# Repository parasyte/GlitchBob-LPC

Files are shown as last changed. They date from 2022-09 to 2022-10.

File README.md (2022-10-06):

# GlitchBob LPC

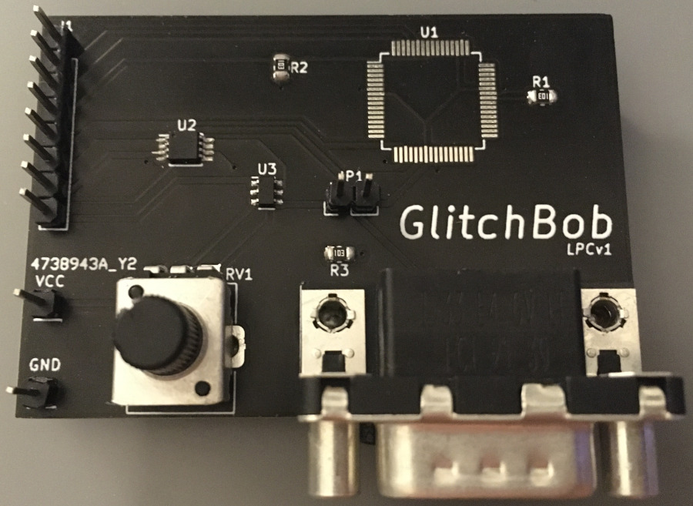
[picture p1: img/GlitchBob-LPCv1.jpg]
GlitchBob LPCv1 device fully assembled


Voltage glitching automation tool to break protection on NXP LPC microcontrollers.

The glitch circuit can be controlled by a Raspberry Pi Pico or other low-cost development board.

## TODO

These are issues identified in the prototype:

- Add bypass caps to all ICs.
- Add pull-up resistor to `74LVC1G3157` switch input.
- Add pull-down resistors to `74LVC2G66` switch inputs.
- Move target closer to I/O header to reduce the trace length for the oscillator I/O.
    - Shorter traces have lower impedance and will be capable of faster clock frequency (up to target max, e.g. 12 MHz).
- The potentiometer polarity is swapped.
    - 0v should be fully counterclockwise, and +VCC should be fully clockwise.
- The potentiometer is upside down.
    - Rotate the footprint 180 degrees.
- No good place to put the rubber feet.
    - Move through-hole components or find smaller feet.
- Still has some wasted surface area with traces spread out.
    - Change 8-pin header pinout to optimize routing.
    - Move traces closer together to prevent ground plane islands.
- `R3` is a bit too close to the serial port.
    - Move `R3` so it is more easily reachable for assembly.

And this is a wish-list for improvements:

- Replace 8-pin header with Raspberry Pi Pico header footprint.
- Add a 7-segment display for glitch-voltage display and other info.
    - 7-Segment driver can be inexpensively built with:
        - [`74LVC244`](https://www.mouser.com/ProductDetail/Texas-Instruments/SN74LVC244APWR?qs=DcvZ7Fltd5xns%252BvAsbES0A%3D%3D) or [`74HC244`](https://www.mouser.com/ProductDetail/Nexperia/74HC244PW118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) - Octal buffer/line-driver.
        - [`74LV4052`](https://www.mouser.com/ProductDetail/Nexperia/74LV4052PW118?qs=me8TqzrmIYXk9tz3ZPOozg%3D%3D) or [`74HC4052`](https://www.mouser.com/ProductDetail/Nexperia/74HC4052D653?qs=P62ublwmbi9dOtwH%252Bhrppg%3D%3D) - 4-channel analog multiplexer/demultiplexer.
        - [`LTC-5723HR`](https://www.mouser.com/ProductDetail/Lite-On/LTC-5723HR?qs=WxFF5lh7QM2ytJdX1EhJKQ%3D%3D) - 4-digit 7-segment display with common cathode.
- Optional ADC for potentiometer measurement.
    - Using Raspberry Pi Pico's ADC for target voltage up to 3.3v <code>V<sub>RL</sub></code>.
    - A standalone ADC will allow a second power rail for the target voltage, e.g. up to 5v <code>V<sub>RL</sub></code> with [`TLA2021`](https://www.mouser.com/ProductDetail/Texas-Instruments/TLA2021IRUGT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) - 12-bit ADC, I<sup>2</sup>C.
- Replacing the analog potentiometer with a digital encoder + DAC can allow finer adjustment of the glitch-voltage.
    - No ADC is required with this setup.
    - Fully software-controlled; E.g. allows ignoring rotations while automated search is running.
    - Example components:
        - [`PEC12R-4215F-S0024`](https://www.mouser.com/ProductDetail/Bourns/PEC12R-4215F-S0024?qs=pxDZlBjcsCiq%252B%252BLwoVCNNg%3D%3D) - Contact incremental encoder with switch, 2-bit quadrature code, 24 pulses per rotation.
        - [`1106`](https://www.mouser.com/ProductDetail/Davies-Molding/1106?qs=byeeYqUIh0Mr0LdKOAGzbA%3D%3D) Knob for encoder, black and blue.
        - [`MCP47CVB21`](https://www.mouser.com/ProductDetail/Microchip-Technology-Atmel/MCP47CVB21-E-MG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) - 12-bit DAC, I<sup>2</sup>C.
    - Encoder switch can be used to change the sensitivity.
        - Debounce in software.
        - Operation is software controlled. E.g. push to switch to next in a list of two or more settings, push-and-hold to start automated search, etc.
        - Sensitivities are software controlled. E.g. 0.25v per pulse, 0.01v per pulse, etc. As low as <code>V<sub>RL</sub>/4096</code> (limited by DAC resolution).

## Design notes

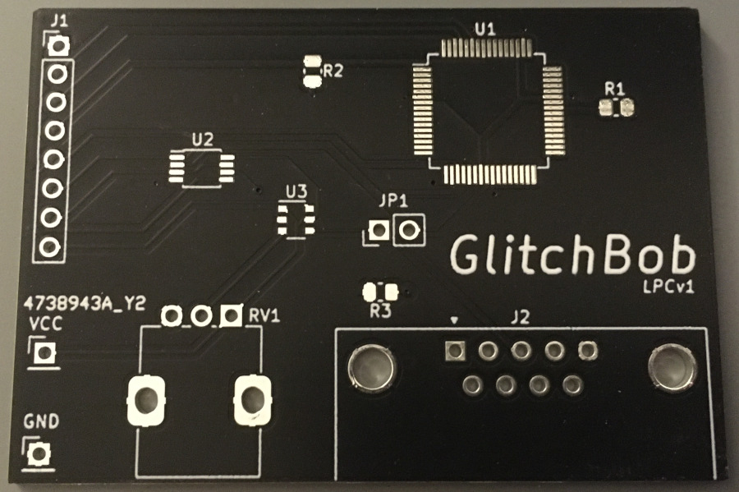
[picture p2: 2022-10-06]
img/GlitchBob-LPCv1-pcb.jpg

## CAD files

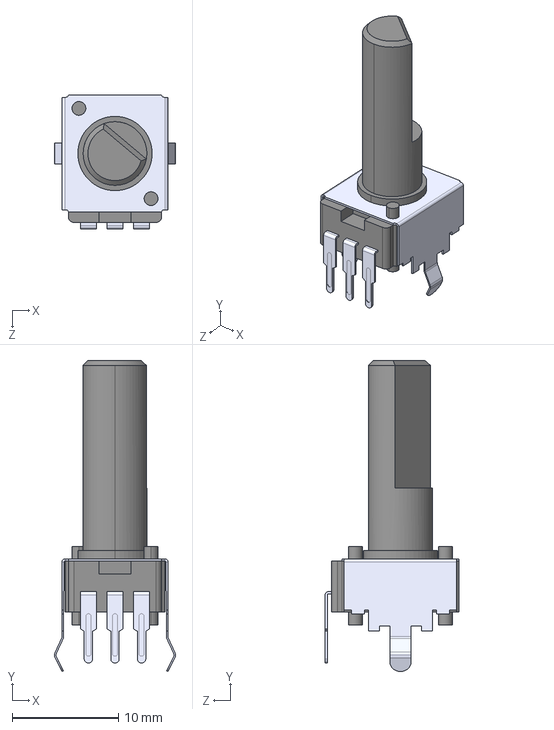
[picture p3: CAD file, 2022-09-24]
board/3d-models/potentiometer.step
11.4 x 29.3 x 12.6 mm

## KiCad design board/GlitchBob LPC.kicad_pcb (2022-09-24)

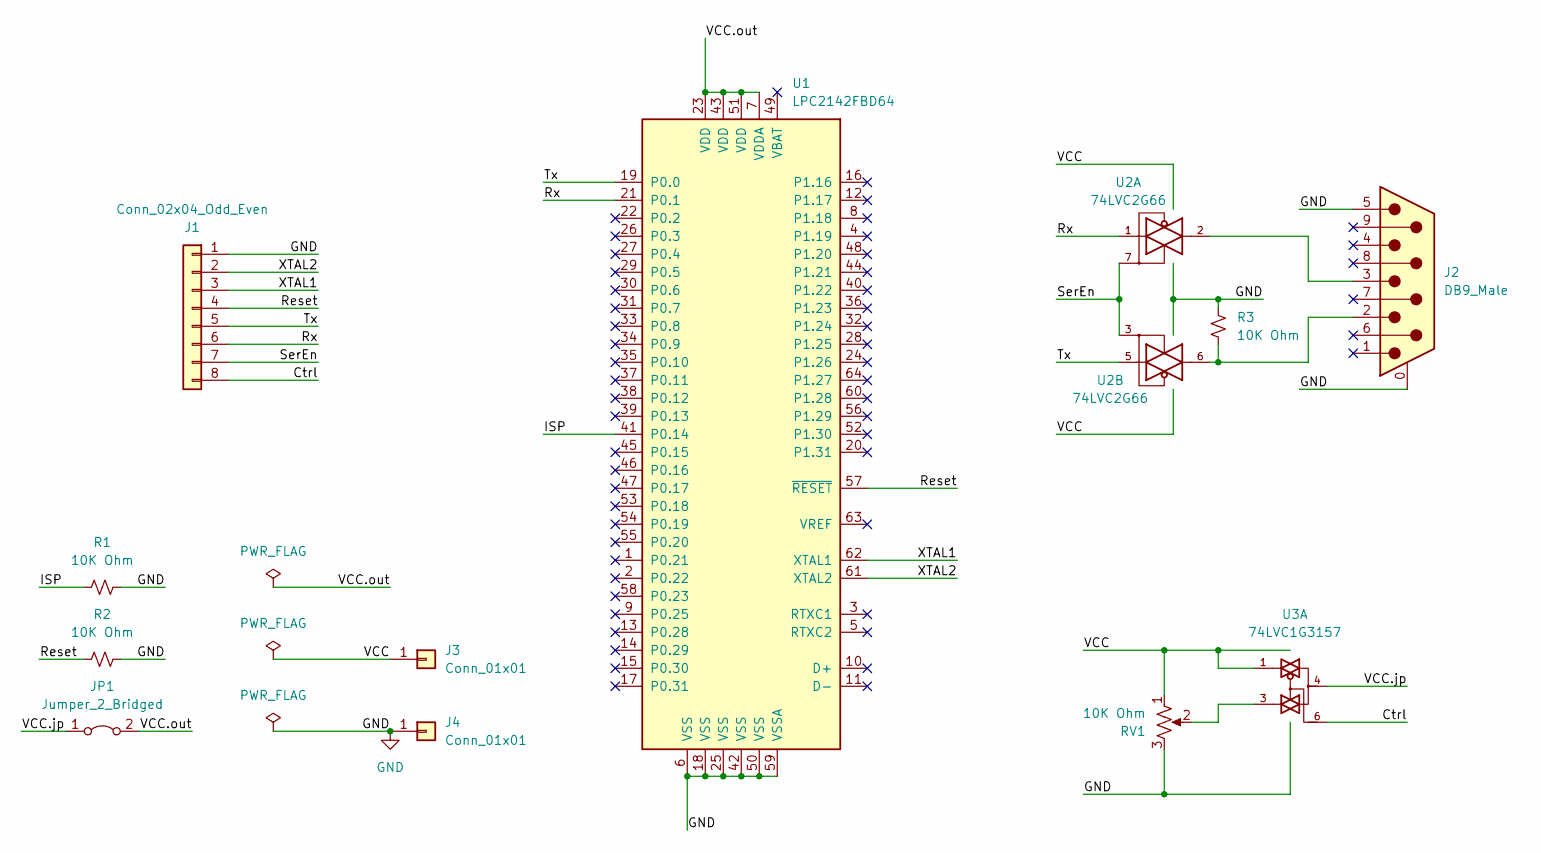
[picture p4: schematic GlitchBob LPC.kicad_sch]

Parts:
J1: Conn_02x04_Odd_Even; PinHeader_1x08_P2.54mm_Vertical
J2: DB9_Male; DSUB-9_Male_Horizontal_P2.77x2.84mm_EdgePinOffset7.70mm_Hou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
J3, J4: Conn_01x01; PinHeader_1x01_P2.54mm_Vertical
JP1: Jumper_2_Bridged; PinHeader_1x02_P2.54mm_Vertical
R1, R2, R3: 10K Ohm; R_0805_2012Metric
RV1: 10K Ohm; Potentiometer_Alps_RK09K_Single_Vertical
U1: LPC2142FBD64; LQFP-64_10x10mm_P0.5mm
U2: 74LVC2G66; TSSOP-8_3x3mm_P0.65mm
U3: 74LVC1G3157; TSOP-6_1.65x3.05mm_P0.95mm

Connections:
/Ctrl: J1.8, U3.6
/ISP: R1.1, U1.41 (P0.14)
/Reset: J1.4, R2.1, U1.57 (~RESET)
/Rx: J1.6, U1.21 (P0.1), U2.1
/SerEn: J1.7, U2.3, U2.7
/Tx: J1.5, U1.19 (P0.0), U2.5
/VCC.jp: JP1.1 (A), U3.4
/VCC.out: JP1.2 (B), U1.7 (VDDA), U1.23 (VDD), U1.43 (VDD), U1.51 (VDD)
/XTAL1: J1.3, U1.62 (XTAL1)
/XTAL2: J1.2, U1.61 (XTAL2)
GND: J1.1, J2.0 (PAD), J2.5, J4.1, R1.2, R2.2, R3.2, RV1.3, RV1.MP, U1.6 (VSS), U1.18 (VSS), U1.25 (VSS), U1.42 (VSS), U1.50 (VSS), U1.59 (VSSA), U2.4 (GND), U3.2 (GND)
unnamed: J2.2, R3.1, U2.6
unnamed: J2.3, U2.2
unnamed: RV1.2, U3.3
VCC: J3.1, RV1.1, U2.8 (VCC), U3.1, U3.5 (VCC)

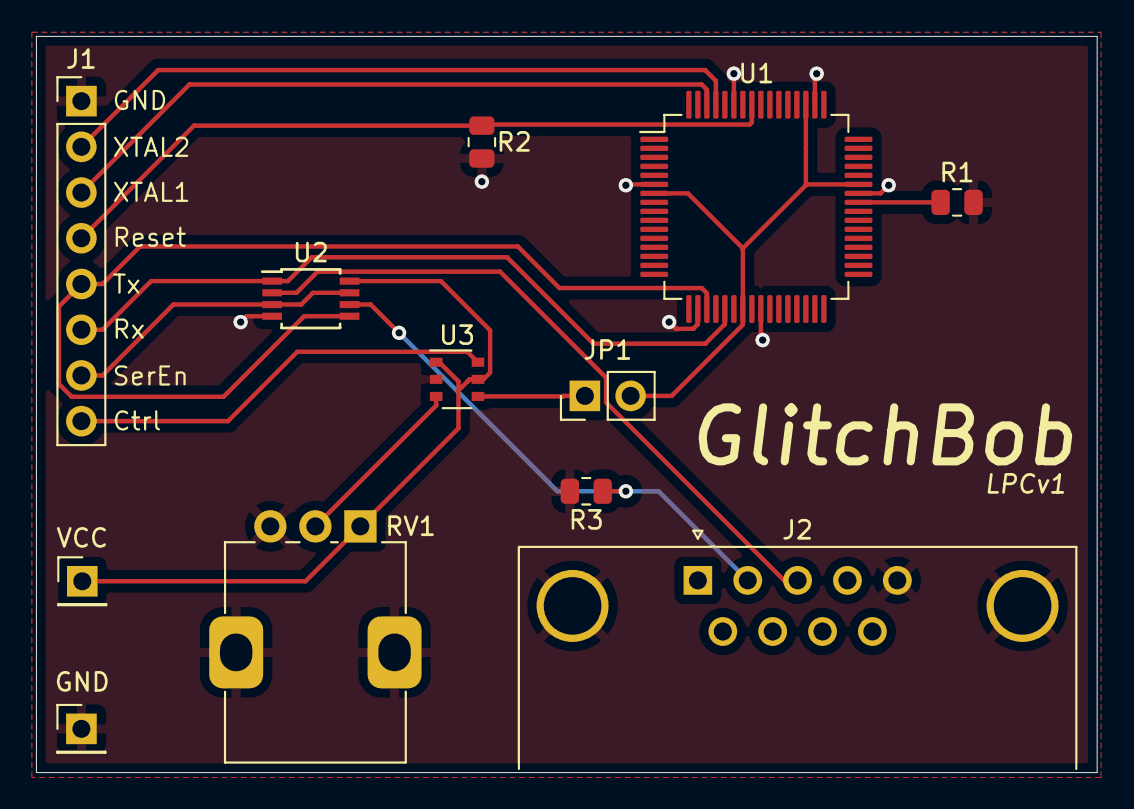
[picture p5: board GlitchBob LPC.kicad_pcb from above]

Board: 2 copper layers, 58.9 x 40.9 mm, 12 parts (0 on the bottom side), 15 nets.

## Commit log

2022-09-24 Add digital encoder and DAC option to wish-list.
    - Researched component options and provided recommendations based on
    availability, price, and feature set.
2022-10-06 Add photo of assembled device
